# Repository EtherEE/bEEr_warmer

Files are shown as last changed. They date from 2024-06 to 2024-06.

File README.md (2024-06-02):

# bEEr_warmer
A simple PCB as a beer mug warmer powered by The USB type C Power Delivery source
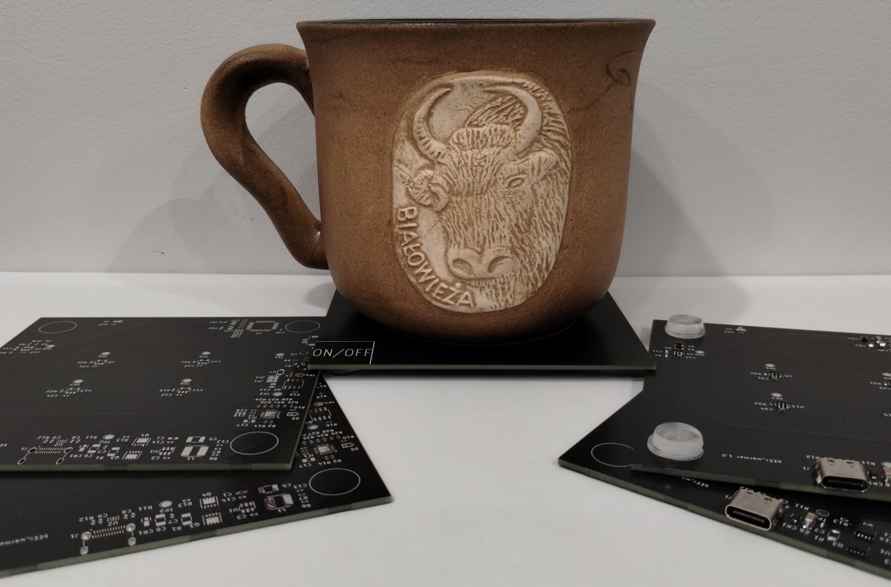
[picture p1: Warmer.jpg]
Warmer

## Table of contents
* [General info](#general-info)
* [Topology](#topology)
* [PCB](#pcb)
* [Setup](#setup)
* [Status](#status)
* [License](#license)
## General info
Gadget built for my colleague - PCB board as a heat keeper for hot drinks like mulled wine, beer or regular tea.
The board requires electronic configuration (selection of resistors) and uploading software to the microcontroller.
## Topology
Diagram
## PCB
The PCB was designed in current KiCad version. All necessary files are in the documentation folder.
## Setup
The gadget uses the AP33771 chip as a Pawer Delivery sink. The output voltage and delivered power is configured using resistors. For the resistor values shown in the schematic, the controller delivers 9V at a maximum power of 20W. Such settings worked well in my implementation of the board. With no load in the form of a mug of beer, the board heats up to 70 degrees in 30 seconds. Keep in mind that my PD sink circuit configuration depends on the resistance of the load. In the JLCPCB board design, the load resistance was about 4.3 Ohms at an ambient temperature of 21 degrees, and was in accordance with the calculations of the Saturn PCB Design calculator. If the load resistance of the manufactured boards will differ from the intended one, the voltage and power settings provided by the PD source should be adjusted accordingly. On the first page of the schematic diagram there are two tables from which you can read the desired values of the voltage and power configuration resistors. For 9V, R28 and R29 must not be soldered in. To get 20W R30 must be 26k Ohm. After checking the value of the load resistance and selecting the appropriate PD sink configuration resistors, the two solder bridges (JP1 and JP2) should be soldered together. This will lead the current to the load. Two additional resistors should not be soldered on the PCB: R13 and R32.

To program the STM32 microcontroller, use the ST Link programmer, the SWDIO and SWCLK pins are brought out on the popular DF13A socket. The program is trivial and its listing can be found in the documentation folder. Digital and one analog outputs from all temperature sensors and a proximity sensor have been fed to the microcontroller. The microcontroller has a large percentage of unused memory resources. There is a huge room for maneuver and for expanding the functionality of the software. By changing the software, the number of temperature sensors can be reduced, thus reducing the cost of the board.

The AND gate is used to protect the circuit from overheating and against software or microcontroller errors. When any of the inputs is low, the current from the load is disconnected. The inputs of the gate are:
- 85 degree sensor output
- touch sensor output
- output from the microcontroller

Two LEDs are used to monitor the status of the device:
- LED_TEST. Is used to control LED flickering. The user is notified of the system status from the LED flashing pattern. Any non-PD power source is not supported in the AP33771, and the LED will show the mismatch accordingly.
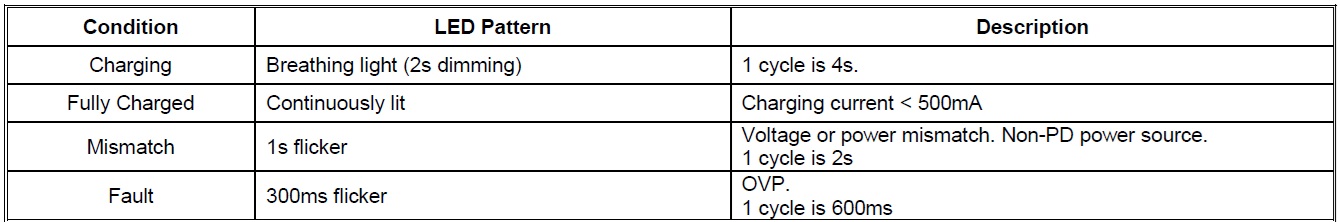
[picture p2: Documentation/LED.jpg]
LED

- LED. It is controlled by a microcontroller. Flashing at a frequency of once per second means that current is being applied to the load. If the diode shines continuously, the device has reached a temperature of about 70 degrees. If the diode flashes quickly (about 2 times per second) there is an error in reading the temperature sensor.

After checking the fucnition of the board, I suggest you desolder the DF13A socket and put conformal coating on both sides of the board to protect the circuit from possible damage from flooding.
## Status
Task closed
## License
MIT

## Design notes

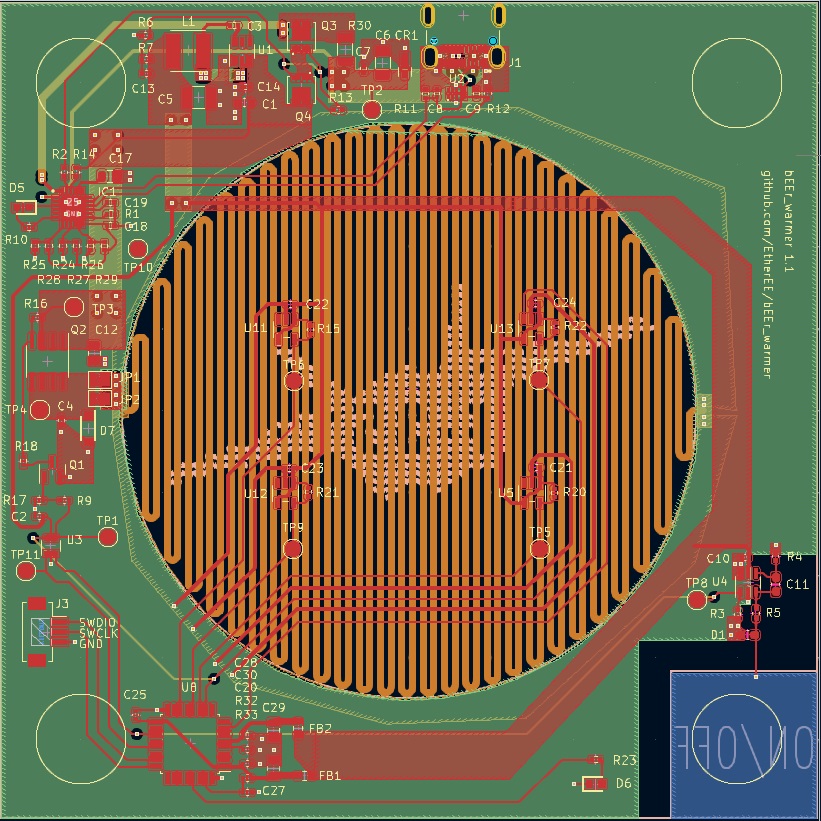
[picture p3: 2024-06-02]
Documentation/PCB/PCB.jpg

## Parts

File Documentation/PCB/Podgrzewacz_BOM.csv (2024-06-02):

Id | Designator | Footprint | Quantity | Designation | Supplier and ref
1 | C8,C9 | C_0402_1005Metric | 2 | 27p
2 | TP11,TP5,TP9,TP7,TP8,TP10,TP6,TP4,TP2,TP1,TP3 | TestPoint_Pad_D2.0mm | 11 | TestPoint
3 | U8 | LQFP-32_7x7mm_P0.8mm | 1 | STM32F030K6Tx
4 | R33,R14,R27 | R_0402_1005Metric | 3 | 0R
5 | R6 | R_0402_1005Metric | 1 | 22k1
6 | C11 | C_0603_1608Metric_Pad1.08x0.95mm_HandSolder | 1 | 2n2-47n
7 | C28 | C_0402_1005Metric | 1 | 10n
8 | R10,R9,R23 | R_0402_1005Metric | 3 | 1k
9 | R11,R12 | R_0402_1005Metric | 2 | 5k1
10 | CR1 | CR_0A-M3&slash_89A_VIS | 1 | MSMP20A-M3/89A
11 | U4 | SOT-23-6 | 1 | AT42QT1012-T
12 | C13 | C_0402_1005Metric | 1 | 56p
13 | C10,C4,C24,C19,C25,C14,C7,C18,C22,C2,C21,C3,C23,C30,C20 | C_0402_1005Metric | 15 | 100n
14 | R3,R7,R25,R24,R16,R26,R17 | R_0402_1005Metric | 7 | 100k
15 | Q3,Q4 | DMG7401SFG13 | 2 | DMN3008SFGQ-7
16 | J3 | Hirose_DF13C_CL535-0403-5-51_1x03-1MP_P1.25mm_Vertical | 1 | DF13A-3P-1.25H_51_
17 | U13 | MF05A | 1 | LM26CIM5-TPA/NOPB
18 | U12,U5 | MF05A | 2 | LM26CIM5-SPA/NOPB
19 | C27 | C_0805_2012Metric | 1 | 4,7u
20 | FB2,FB1 | R_0603_1608Metric | 2 | BLM18EG221SN1D
21 | D5,D6 | LEDC1608X80N | 2 | 150060AS75000
22 | C6 | C_1206_3216Metric | 1 | 10u
23 | R18 | R_0402_1005Metric | 1 | 10k
24 | U11 | MF05A | 1 | LM26CIM5-RPA/NOPB
25 | R1 | R_0402_1005Metric | 1 | 56k
26 | D1 | C_0603_1608Metric_Pad1.08x0.95mm_HandSolder | 1 | TESDU5V0 RGG
27 | U3 | SOT-363_SC-70-6 | 1 | 74LVC1G11DW-7
28 | C29,C12,C17 | C_0805_2012Metric | 3 | 1u
29 | U2 | DQA_R-PUSON-N10_ | 1 | TPD4E02B04DQA
30 | Q2 | SOIC-8_3.9x4.9mm_P1.27mm | 1 | AO4447A
31 | C1 | C_0603_1608Metric | 1 | 1u
32 | C5 | C_1210_3225Metric | 1 | 47u
33 | Q1 | SOT-23 | 1 | MMFTN3402
34 | R21,R15,R20,R22 | R_0402_1005Metric | 4 | 22k
35 | R4 | R_0402_1005Metric | 1 | 1M
36 | J1 | HRS_CX90B1-24P | 1 | CX90B1-24P
37 | L1 | LQH5BPB100MT0L | 1 | 15uH
38 | JP1,JP2 | SolderJumper-2_P1.3mm_Open_TrianglePad1.0x1.5mm | 2 | SolderJumper_2_Bridged
39 | R30 | R_1206_3216Metric | 1 | 10mR
40 | U1 | SOT-23-6 | 1 | TPS54202DDCR
41 | R2 | R_0402_1005Metric | 1 | 100R
42 | R5 | R_0402_1005Metric_Pad0.72x0.64mm_HandSolder | 1 | 4k7-33k
43 | IC1 | QFN50P400X400X80-25N-D | 1 | AP33771DKZ-13
44 | D7 | SODFL3617X108N | 1 | NRVS1MFL

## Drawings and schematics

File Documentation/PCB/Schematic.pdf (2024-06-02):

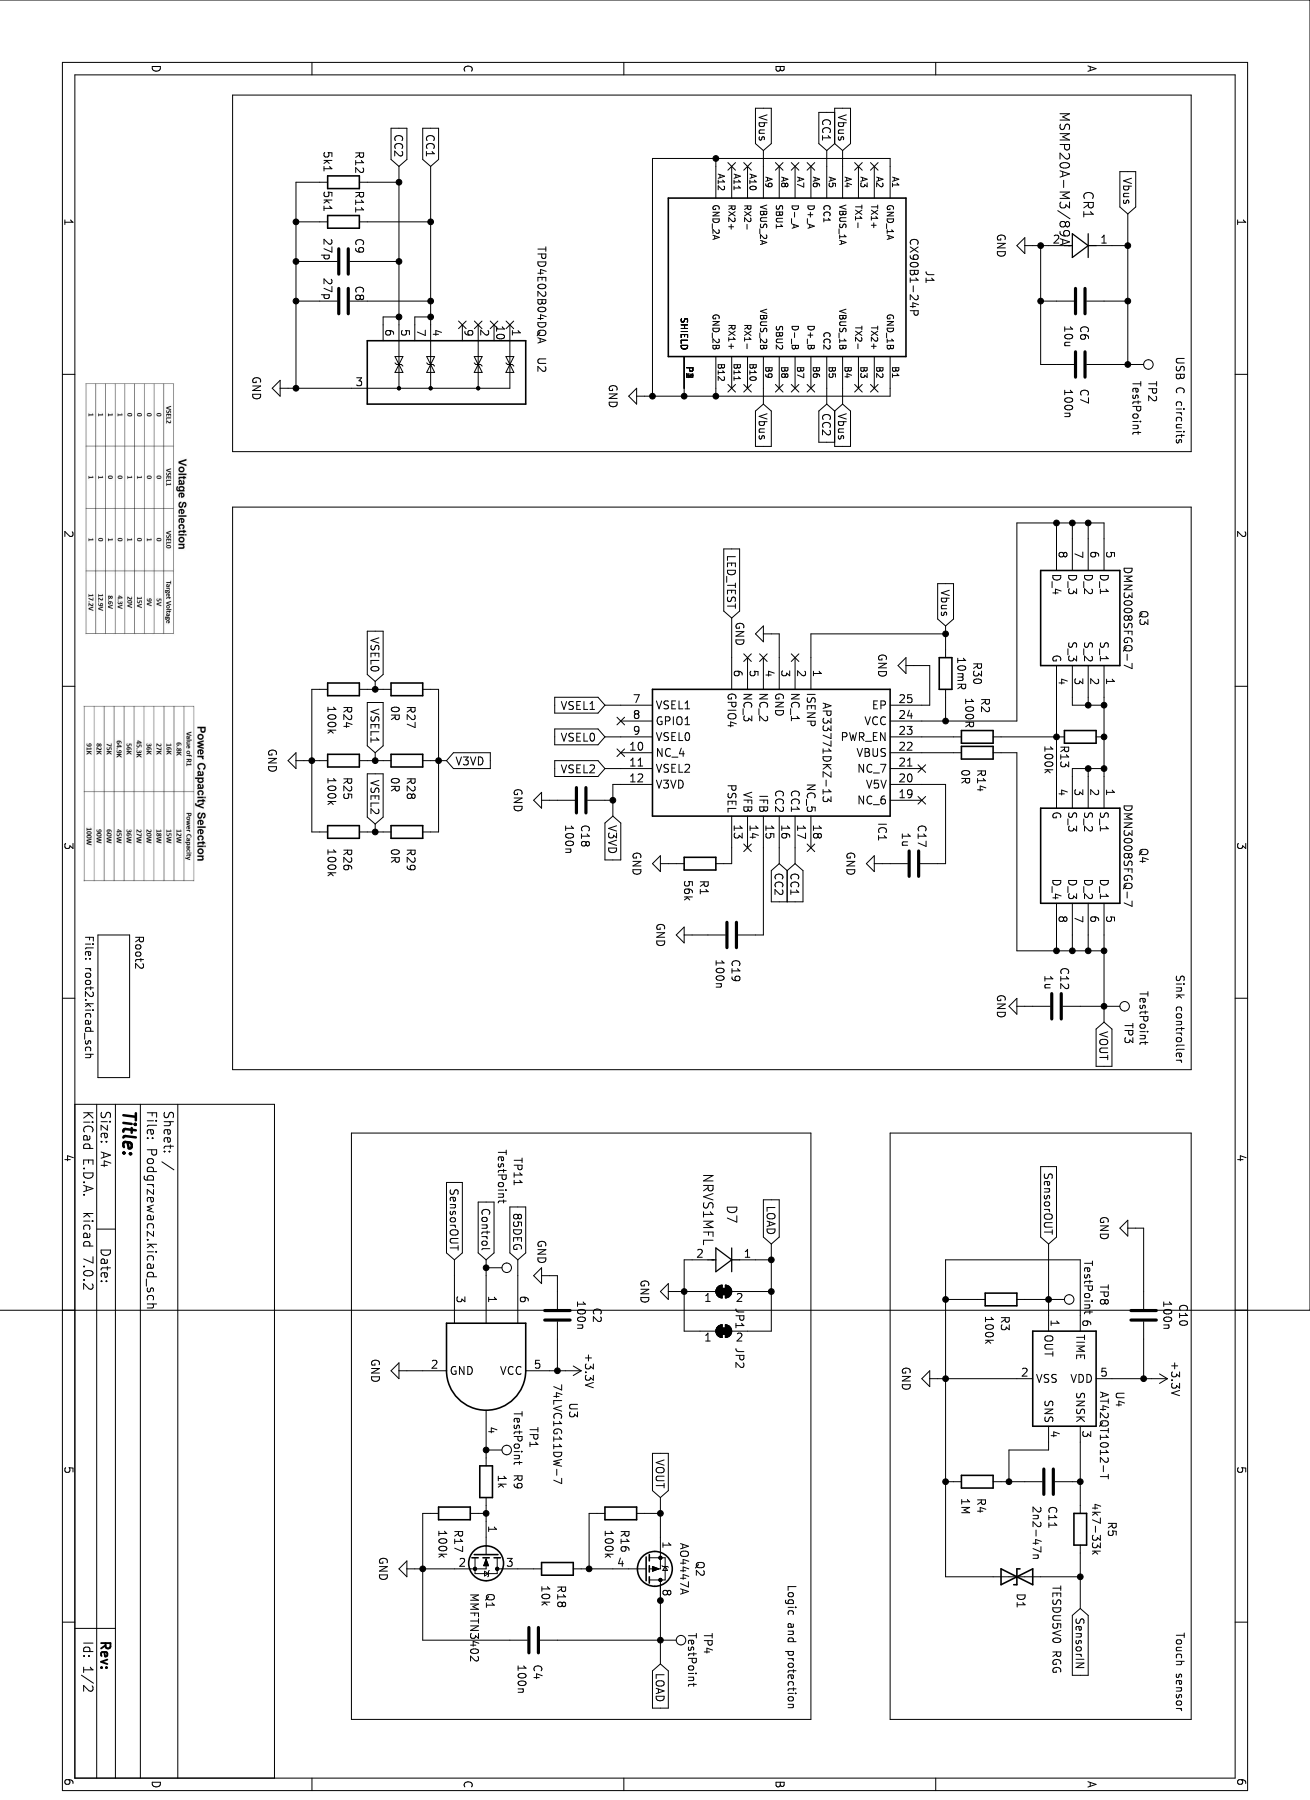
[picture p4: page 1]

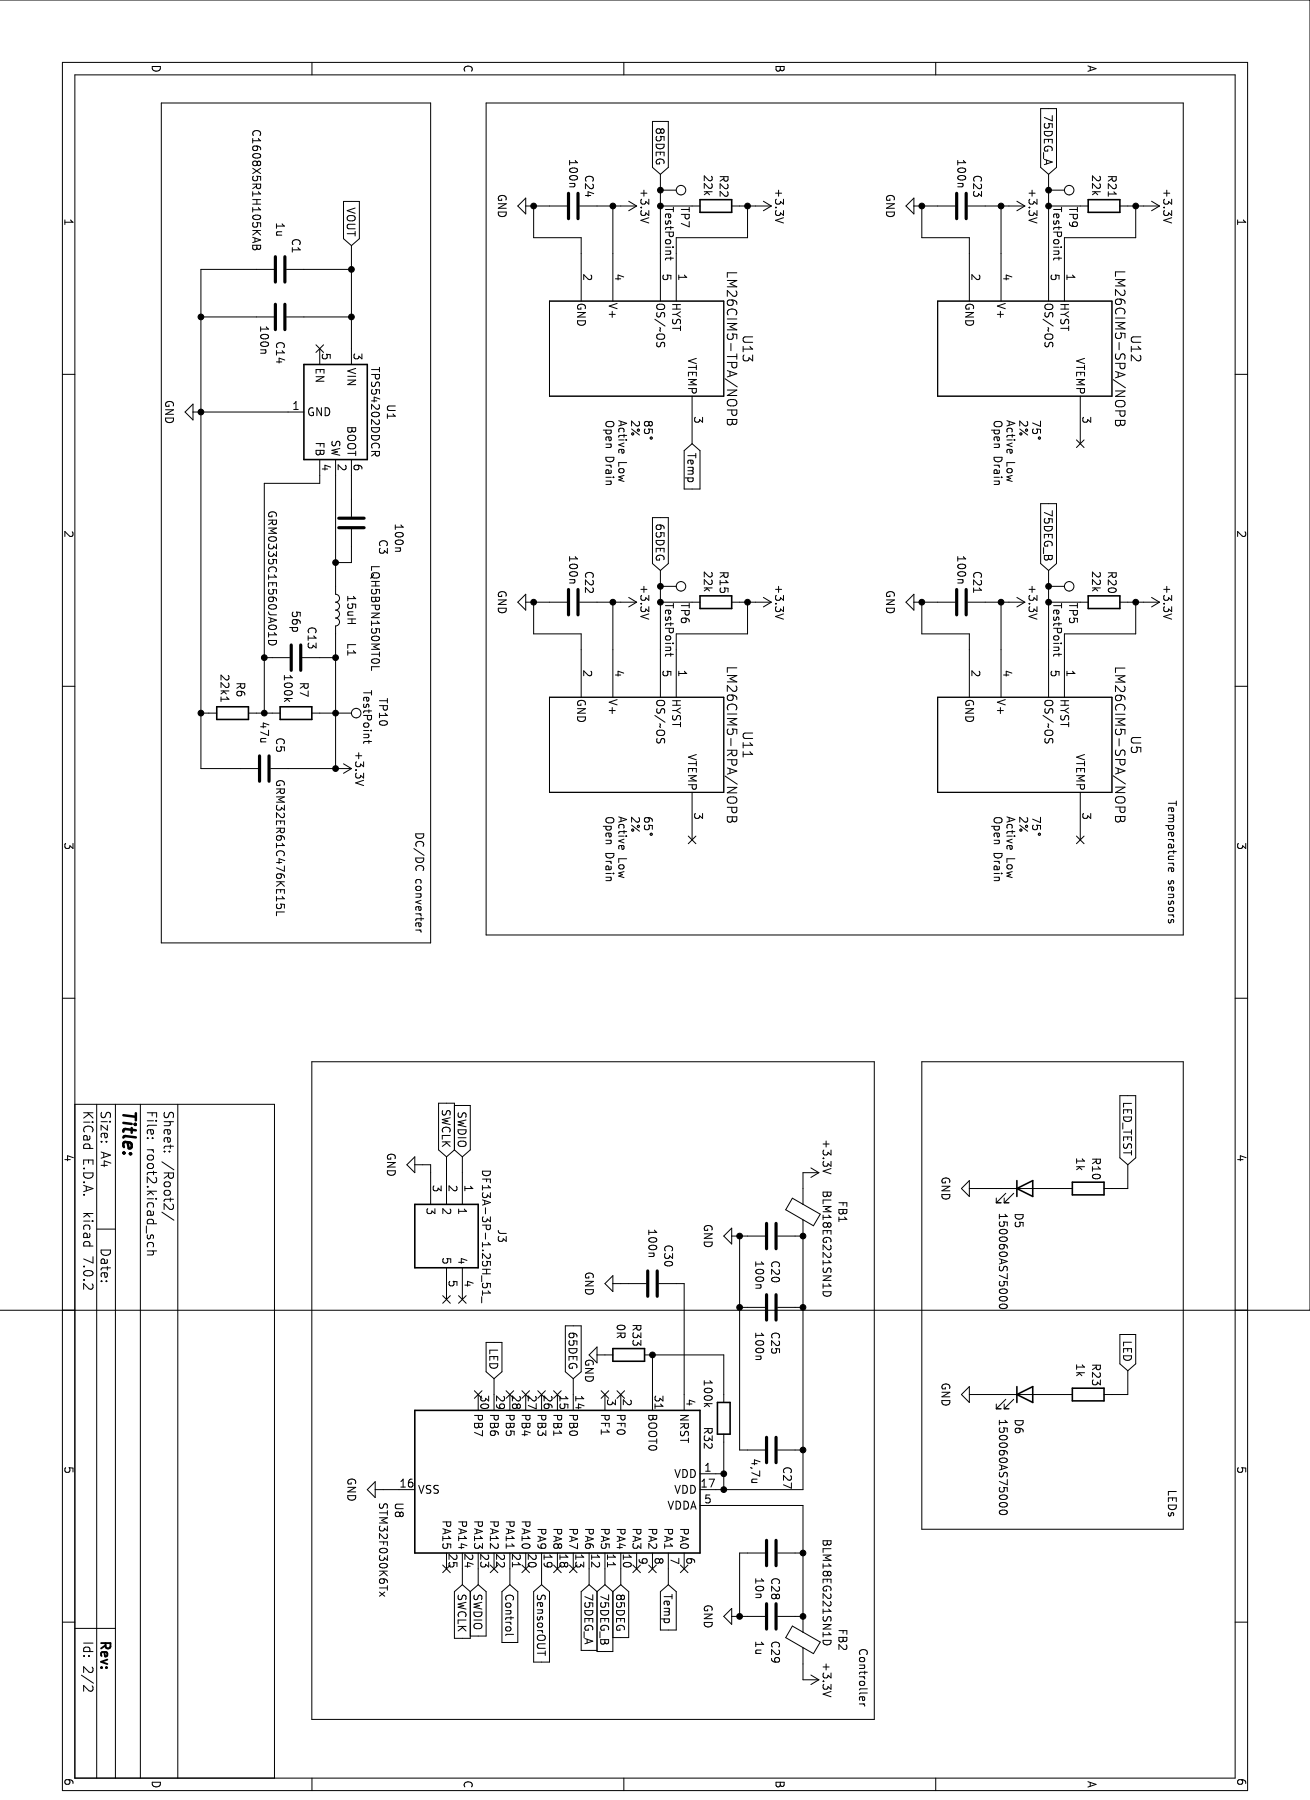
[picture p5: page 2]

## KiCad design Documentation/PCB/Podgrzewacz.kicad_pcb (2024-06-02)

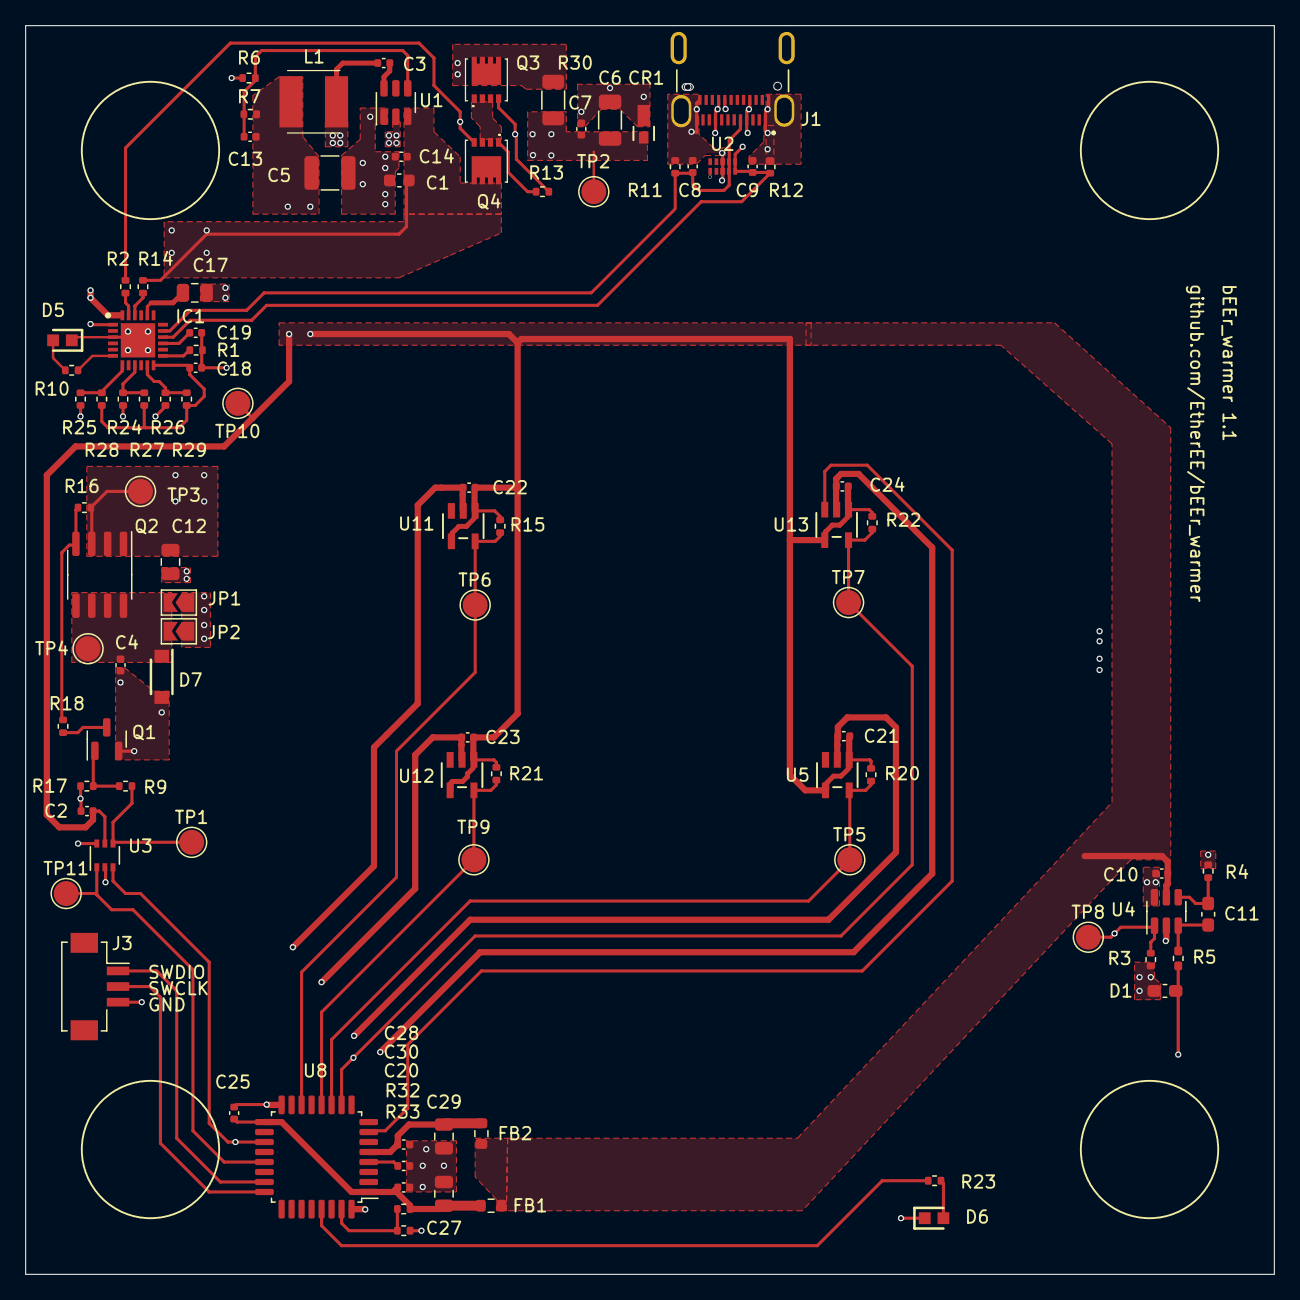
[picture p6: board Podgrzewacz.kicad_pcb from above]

Board: 4 copper layers, 100.0 x 100.0 mm, 94 parts (0 on the bottom side), 46 nets.

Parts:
C1: 1u; C_0603_1608Metric
C2, C3, C4, C7, C10, C14, C18, C19, C20, C21, C22, C23, C24, C25, C30: 100n; C_0402_1005Metric
C5: 47u; C_1210_3225Metric
C6: 10u; C_1206_3216Metric
C8, C9: 27p; C_0402_1005Metric
C11: 2n2-47n; C_0603_1608Metric_Pad1.08x0.95mm_HandSolder
C12, C17, C29: 1u; C_0805_2012Metric
C13: 56p; C_0402_1005Metric
C27: 4,7u; C_0805_2012Metric
C28: 10n; C_0402_1005Metric
CR1: MSMP20A-M3/89A; CR_0A-M3&slash_89A_VIS
D1: TESDU5V0 RGG; C_0603_1608Metric_Pad1.08x0.95mm_HandSolder
D5, D6: 150060AS75000; LEDC1608X80N
D7: NRVS1MFL; SODFL3617X108N
FB1, FB2: BLM18EG221SN1D; R_0603_1608Metric
IC1: AP33771DKZ-13; QFN50P400X400X80-25N-D
J1: CX90B1-24P; HRS_CX90B1-24P
J3: DF13A-3P-1.25H_51_; Hirose_DF13C_CL535-0403-5-51_1x03-1MP_P1.25mm_Vertical
JP1, JP2: SolderJumper_2_Bridged; SolderJumper-2_P1.3mm_Open_TrianglePad1.0x1.5mm
L1: 15uH; LQH5BPB100MT0L
Q1: MMFTN3402; SOT-23
Q2: AO4447A; SOIC-8_3.9x4.9mm_P1.27mm
Q3, Q4: DMN3008SFGQ-7; DMG7401SFG13
R1: 56k; R_0402_1005Metric
R2: 100R; R_0402_1005Metric
R3, R7, R13, R16, R17, R24, R25, R26, R32: 100k; R_0402_1005Metric
R4: 1M; R_0402_1005Metric
R5: 4k7-33k; R_0402_1005Metric_Pad0.72x0.64mm_HandSolder
R6: 22k1; R_0402_1005Metric
R9, R10, R23: 1k; R_0402_1005Metric
R11, R12: 5k1; R_0402_1005Metric
R14, R27, R28, R29, R33: 0R; R_0402_1005Metric
R15, R20, R21, R22: 22k; R_0402_1005Metric
R18: 10k; R_0402_1005Metric
R30: 10mR; R_1206_3216Metric
TP1, TP2, TP3, TP4, TP5, TP6, TP7, TP8, TP9, TP10, TP11: TestPoint; TestPoint_Pad_D2.0mm
U1: TPS54202DDCR; SOT-23-6
U2: TPD4E02B04DQA; DQA_R-PUSON-N10_
U3: 74LVC1G11DW-7; SOT-363_SC-70-6
U4: AT42QT1012-T; SOT-23-6
U5, U12: LM26CIM5-SPA/NOPB; MF05A
U8: STM32F030K6Tx; LQFP-32_7x7mm_P0.8mm
U11: LM26CIM5-RPA/NOPB; MF05A
U13: LM26CIM5-TPA/NOPB; MF05A

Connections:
65DEG: R15.1, TP6.1, U8.14 (PB0), U11.5 (OS/~OS)
75DEG_A: R21.1, TP9.1, U8.12 (PA6), U12.5 (OS/~OS)
75DEG_B: R20.1, TP5.1, U5.5 (OS/~OS), U8.11 (PA5)
85DEG: R22.1, TP7.1, U3.6, U8.10 (PA4), U13.5 (OS/~OS)
+3.3V: C2.2, C5.1, C10.2, C13.1, C21.1, C22.1, C23.1, C24.1, FB1.1, FB2.2, L1.2, R7.2, R15.2, R20.2, R21.2, R22.2, TP10.1, U3.5 (VCC), U4.5 (VDD), U5.1 (HYST), U5.4 (V+), U11.1 (HYST), U11.4 (V+), U12.1 (HYST), U12.4 (V+), U13.1 (HYST), U13.4 (V+)
CC1: C8.1, IC1.17 (CC1), J1.A5 (CC1), R11.2, U2.4 (IO3), U2.7 (NC)
CC2: C9.1, IC1.16 (CC2), J1.B5 (CC2), R12.2, U2.5 (IO4), U2.6 (NC)
Control: TP11.1, U3.1, U8.21 (PA11)
GND: C1.2, C2.1, C4.2, C5.2, C6.2, C7.2, C8.2, C9.2, C10.1, C12.2, C14.2, C17.2, C18.2, C19.2, C20.1, C21.2, C22.2, C23.2, C24.2, C25.1, C27.2, C28.1, C29.1, C30.1, CR1.2, D1.1 (A1), D5.1 (K), D6.1 (K), D7.2, IC1.3 (GND), IC1.25 (EP), J1.A1 (GND_1A), J1.A12 (GND_2A), J1.B1 (GND_1B), J1.B12 (GND_2B), J1.P1 (SHIELD), J1.P2 (SHIELD), J1.P3 (SHIELD), J1.P4 (SHIELD), J3.3, JP1.1 (A), JP2.1 (A), Q1.2 (S), R1.2, R3.2, R4.2, R6.1, R11.1, R12.1, R17.2, R24.2, R25.2, R26.2, R33.1, U1.1 (GND), U2.3 (G), U2.8 (G), U3.2 (GND), U4.2 (VSS), U4.6 (TIME), U5.2 (GND), U8.16 (VSS), U8.32 (VSS), U11.2 (GND), U12.2 (GND), U13.2 (GND)
LED: R23.2, U8.29 (PB6)
LED_TEST: IC1.6 (GPIO4), R10.2
LOAD: C4.1, D7.1, JP1.2 (B), JP2.2 (B), Q2.5 (D), Q2.6 (D), Q2.7 (D), Q2.8 (D), TP4.1
unnamed: C20.2, C25.2, C27.1, FB1.2, R32.2, U8.1 (VDD), U8.17 (VDD)
unnamed: D5.2 (A), R10.1
unnamed: D6.2 (A), R23.1
unnamed: C19.1, IC1.15 (IFB)
unnamed: IC1.13 (PSEL), R1.1
unnamed: IC1.23 (PWR_EN), R2.2
unnamed: C17.1, IC1.20 (V5V)
unnamed: IC1.22 (VBUS), R14.2
unnamed: IC1.24 (VCC), Q3.5 (D_1), Q3.6 (D_2), Q3.7 (D_3), Q3.8 (D_4), R30.2
unnamed: Q1.3 (D), R18.2
unnamed: Q1.1 (G), R9.2, R17.1
unnamed: Q2.4 (G), R16.2, R18.1
unnamed: Q3.4 (G), Q4.4 (G), R2.1, R13.2
unnamed: Q3.1 (S_1), Q3.2 (S_2), Q3.3 (S_3), Q4.1 (S_1), Q4.2 (S_2), Q4.3 (S_3), R13.1
unnamed: R9.1, TP1.1, U3.4
unnamed: C3.2, U1.6 (BOOT)
unnamed: C13.2, R6.2, R7.1, U1.4 (FB)
unnamed: C3.1, L1.1, U1.2 (SW)
unnamed: C11.2, R4.1, U4.4 (SNS)
unnamed: C11.1, R5.1, U4.3 (SNSK)
unnamed: R32.1, R33.2, U8.31 (BOOT0)
unnamed: C30.2, U8.4 (NRST)
unnamed: C28.2, C29.2, FB2.1, U8.5 (VDDA)
SWCLK: J3.2, U8.24 (PA14)
SWDIO: J3.1, U8.23 (PA13)
SensorIN: D1.2 (A2), R5.2
SensorOUT: R3.1, TP8.1, U3.3, U4.1 (OUT), U8.19 (PA9)
Temp: U8.7 (PA1), U13.3 (VTEMP)
V3VD: C18.1, IC1.12 (V3VD), R27.1, R28.1, R29.1
VOUT: C1.1, C12.1, C14.1, Q2.1 (S), Q2.2 (S), Q2.3 (S), Q4.5 (D_1), Q4.6 (D_2), Q4.7 (D_3), Q4.8 (D_4), R14.1, R16.1, TP3.1, U1.3 (VIN)
VSEL0: IC1.9 (VSEL0), R24.1, R27.2
VSEL1: IC1.7 (VSEL1), R25.1, R28.2
VSEL2: IC1.11 (VSEL2), R26.1, R29.2
Vbus: C6.1, C7.1, CR1.1, IC1.1 (ISENP), J1.A4 (VBUS_1A), J1.A9 (VBUS_2A), J1.B4 (VBUS_1B), J1.B9 (VBUS_2B), R30.1, TP2.1

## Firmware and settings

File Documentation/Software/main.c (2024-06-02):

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
/* Includes ------------------------------------------------------------------*/
#include "main.h"

ADC_HandleTypeDef hadc;

void SystemClock_Config(void);
static void MX_GPIO_Init(void);
static void MX_ADC_Init(void);
/**
  * @brief  The application entry point.
  * @retval int
  */
int main(void)
{
  /* MCU Configuration--------------------------------------------------------*/

  /* Reset of all peripherals, Initializes the Flash interface and the Systick. */
  HAL_Init();

  /* Configure the system clock */
  SystemClock_Config();

  /* Initialize all configured peripherals */
  MX_GPIO_Init();
  MX_ADC_Init();
  /* USER CODE BEGIN 2 */
  HAL_GPIO_WritePin(GPIOA, GPIO_PIN_11, GPIO_PIN_RESET);
  HAL_GPIO_WritePin(GPIOB, GPIO_PIN_6, GPIO_PIN_RESET);
  /* USER CODE END 2 */

  /* Infinite loop */
  /* USER CODE BEGIN WHILE */
  while (1)
  {
	  uint16_t InputState = 0;
	  InputState |= HAL_GPIO_ReadPin(GPIOB, GPIO_PIN_0) << 2;
	  InputState |= HAL_GPIO_ReadPin(GPIOA, GPIO_PIN_6) << 1;
	  InputState |= HAL_GPIO_ReadPin(GPIOA, GPIO_PIN_5) << 0;

	  if (HAL_GPIO_ReadPin(GPIOA, GPIO_PIN_9) == GPIO_PIN_SET)
	  {
		  switch (InputState)
		  {
			  case 0: //000
				  HAL_GPIO_WritePin(GPIOA, GPIO_PIN_11, GPIO_PIN_RESET);
				  HAL_GPIO_WritePin(GPIOB, GPIO_PIN_6, GPIO_PIN_SET);
				  break;
			  case 1: //001
				  HAL_GPIO_WritePin(GPIOA, GPIO_PIN_11, GPIO_PIN_RESET);
				  HAL_GPIO_WritePin(GPIOB, GPIO_PIN_6, GPIO_PIN_SET);
				  break;
			  case 2: //010
				  HAL_GPIO_WritePin(GPIOA, GPIO_PIN_11, GPIO_PIN_RESET);
				  HAL_GPIO_WritePin(GPIOB, GPIO_PIN_6, GPIO_PIN_SET);
				  break;
			  case 3: //011
				  HAL_GPIO_WritePin(GPIOA, GPIO_PIN_11, GPIO_PIN_SET);
				  HAL_GPIO_WritePin(GPIOB, GPIO_PIN_6, GPIO_PIN_SET);
				  break;
			  case 7: //111
				  HAL_GPIO_WritePin(GPIOA, GPIO_PIN_11, GPIO_PIN_SET);
				  HAL_GPIO_TogglePin(GPIOB, GPIO_PIN_6);
				  HAL_Delay(500);
				  break;
			  default:
				  HAL_GPIO_WritePin(GPIOA, GPIO_PIN_11, GPIO_PIN_RESET);
				  HAL_GPIO_TogglePin(GPIOB, GPIO_PIN_6);
				  HAL_Delay(250);
				  break;
		  }
	  }
	  else
	  {
		  HAL_GPIO_WritePin(GPIOA, GPIO_PIN_11, GPIO_PIN_RESET);
		  HAL_GPIO_WritePin(GPIOB, GPIO_PIN_6, GPIO_PIN_RESET);
	  }

    /* USER CODE END WHILE */

    /* USER CODE BEGIN 3 */
  }
  /* USER CODE END 3 */
}

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


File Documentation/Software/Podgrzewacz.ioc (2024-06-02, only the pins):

Mcu.UserName=STM32F030K6Tx
PA1.GPIO_Label=Temp
PA1.Signal=ADC_IN1
PA11.GPIO_Label=Control
PA11.Signal=GPIO_Output
PA13.Signal=SYS_SWDIO
PA14.Signal=SYS_SWCLK
PA4.GPIO_Label=_85DEG
PA4.Signal=GPIO_Input
PA5.GPIO_Label=_75DEG_B
PA5.Signal=GPIO_Input
PA6.GPIO_Label=_75DEG_A
PA6.Signal=GPIO_Input
PA9.GPIO_Label=SensorOUT
PA9.Signal=GPIO_Input
PB0.GPIO_Label=_65DEG
PB0.Signal=GPIO_Input
PB6.GPIO_Label=LED
PB6.Signal=GPIO_Output

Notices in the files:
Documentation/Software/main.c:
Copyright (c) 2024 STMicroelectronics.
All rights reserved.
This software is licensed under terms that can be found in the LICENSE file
